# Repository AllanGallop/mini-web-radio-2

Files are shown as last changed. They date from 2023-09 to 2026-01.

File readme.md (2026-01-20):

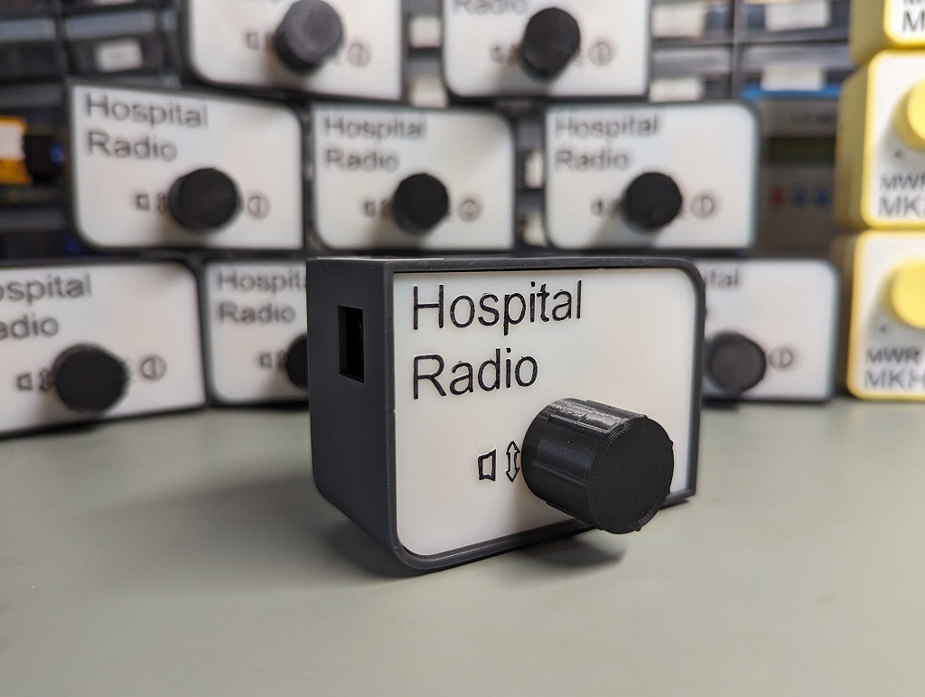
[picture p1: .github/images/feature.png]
Feature_Image


# Mini Web Radio 2

### [Version 3 now available](https://github.com/AllanGallop/mini-web-radio-3)

Originally designed as a charity project, the MWR is a simple internet radio based on the ESP32 microcontroller. Version 2 builds upon the [original project](https://github.com/AllanGallop/mini-web-radio) introducing stereo audio, supporting multiple channels and utilises a custom PCB with (mostly) surface mount components.

> Be warned, This project is still in the prototype phase

## Hardware

### Core hardware Components

* Expressif ESP32-S2 (or similar dual core variant)
* Texas Instruments PCM5102APWR audio stereo dac
* NXP TDA1308 Class AB Stereo headphone driver
* PEC12R - 12 mm Incremental Encoder
* TP4056 Lithium battery charger
* ME6211C33 500mA LDO regulator
* CH340C USB-UART

### Schematic

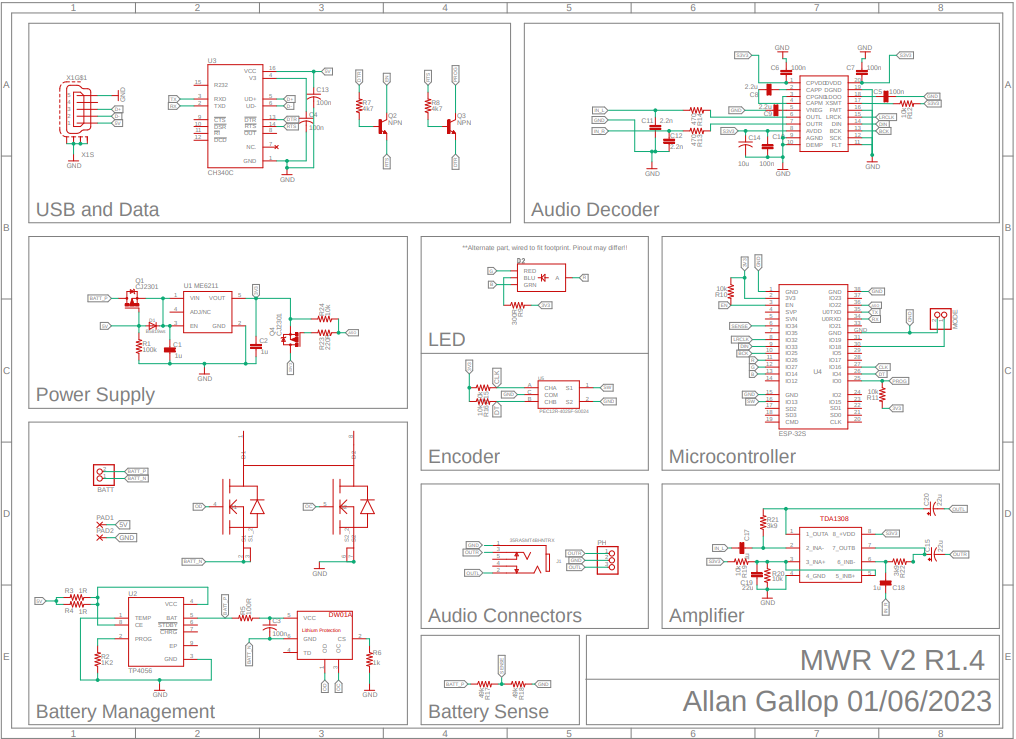
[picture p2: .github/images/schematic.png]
Schematic


## Construction

### PCB

The PCB can be produced and assembled by a fabrication service such as JLCpcb, who are also able to source a marjority of the parts. Alternatively you can fabricate the PCB and acquire / assemble it yourself. Regardless of which method chosen you will need to solder on the through-hole components yourself.. fortuently this is just the rotatry encoder and the pin headers so only minimal soldering skills are required.

All construction files, including a BOM / CPL are provided in the [pcb](pcb/) directory. Additional parts needed to complete the build are maintained in a [seperate file](pcb/additional_parts.txt).

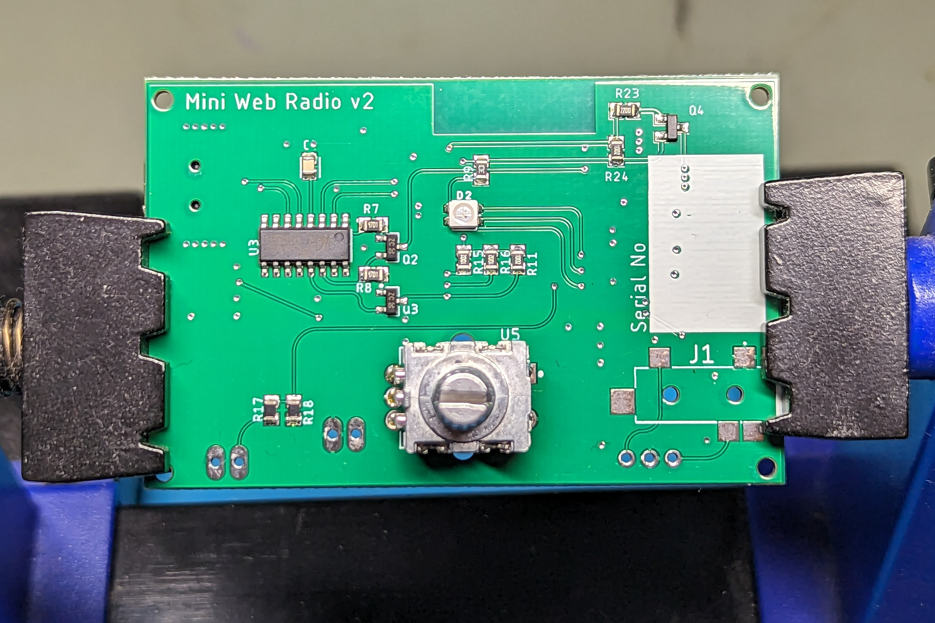
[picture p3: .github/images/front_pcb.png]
[](.github/images/front_pcb.png)
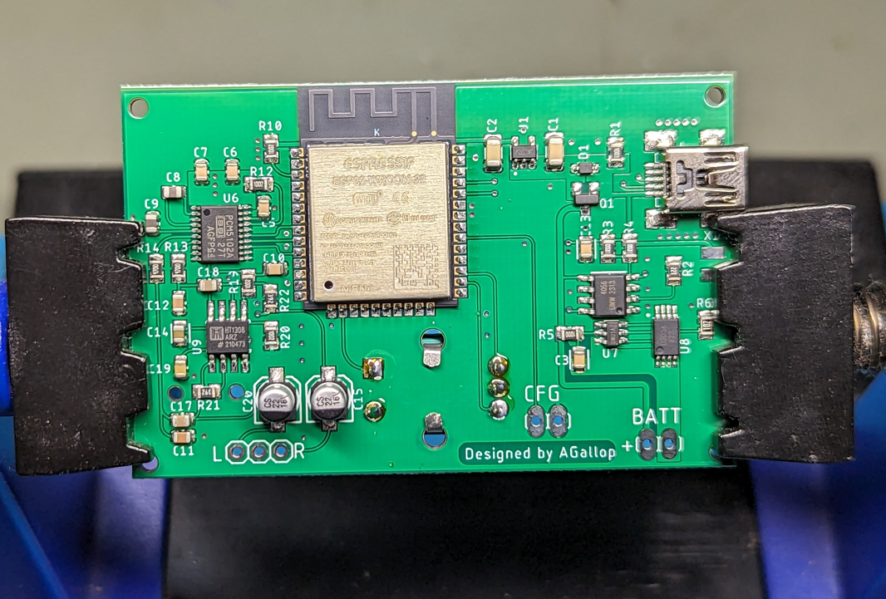
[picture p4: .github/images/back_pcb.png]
[](.github/images/back_pcb.png)

__Component Placement__

The JLCpcb assembly tool sometimes misaligns components (especially if a part is substituted). Use these images to confirm placements align with fiducial markers of the pcb. 

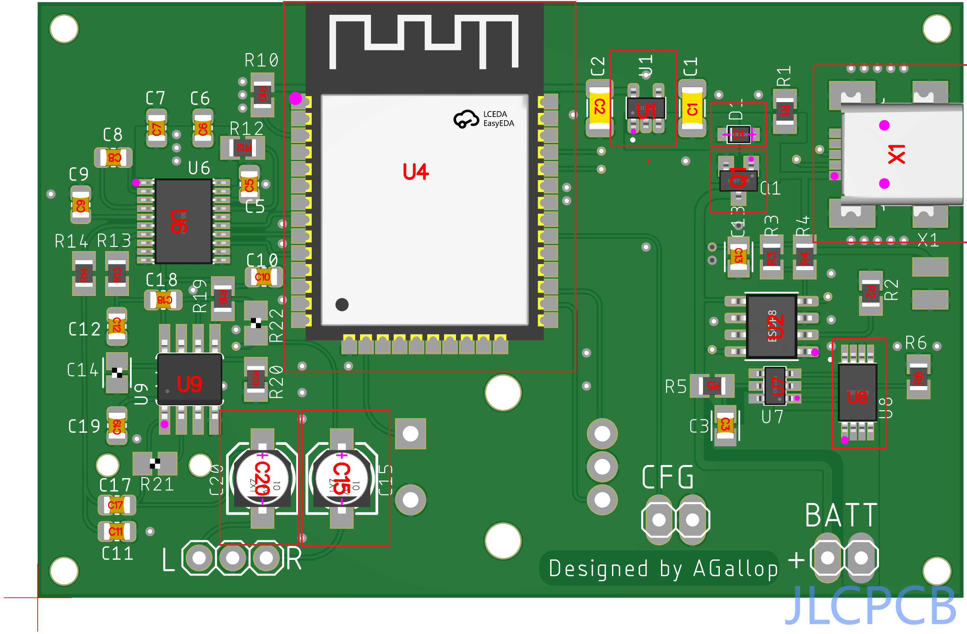
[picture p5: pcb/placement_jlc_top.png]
[](pcb/placement_jlc_top.png)
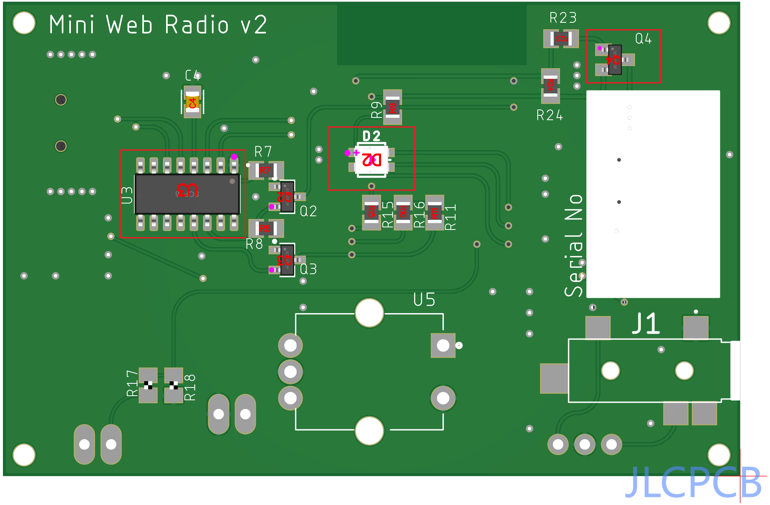
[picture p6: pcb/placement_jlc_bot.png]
[](pcb/placement_jlc_bot.png)

_Commonly misaligned are U1, D1, D2, Q1, X1, U2, U4, Q4, U8, C15 and C20_

### Case

The case is 3D printed, as above this can be done by a fabrication service if you do not own a printer. 

> Consider asking your local makerspace about 3D printing!

### Firmware

The firmware is provided in the [firmware](firmware/) directory. You will need [PlatformIO](https://platformio.org/) to build and upload it.

> Raise an issue if you would prefer an Arduino IDE version... or PR one yourself

## Operation

### Controls

The radio is designed to be easy to use, there is only one control!

* Push dial to switch it on
* Hold dial to switch it off
* Push dial while running to change channel
* Twist dial to change volume

### Status Light

| Colour | Description |
|:---|---:|
| Blue | Waiting for network |
| Green | Running - Battery Good |
| Amber | Running - Battery Reasonable |
| Red | Running - Battery Low |
| Off | Radio Off / Standby |

## Configuration

The MWR has built-in browser based configuration which allows you to define the Hostname, Wireless network credentials and the playback URL.

> Enable Configuration mode

1. Switch Off MWR
2. Open Faceplate 
3. Install jumper (2.54mm) or short config pins
4. Turn On MWR
5. Connect to `MWR-WIFI-SETUP` wireless network
6. Remove Jumper
6. Navigate browser to `192.168.1.1`
7. Enter configuration Details and select `Save`
8. The MWR will automatically restart into radio mode and begin playback

> **Use SPIFF Files** </br> Alternatively you can enter configuration details directly into the configuration files (host, ssid, pass, url) located in the _data_ directory, this is preferred when mulitiple units require setup. 

### Multiple URL's
Multiple station URL's can be entered, there should be **one** url per line. The following streams are supported:

* MP3 / M3U
* M3U8
* AAC
* FLAC
* OPUS
* OGG

### Finding URL's
There are lists available online, such as this one, however if you are unable to locate the stream URL of a preferred station I suggest locating the website in which the stream can be listened from, opening your browsers dev tools (usually F12), selecting the _Network_ and finally filter the list be 'Media' types. You may need to reload the page and start/stop playback for it to show up.

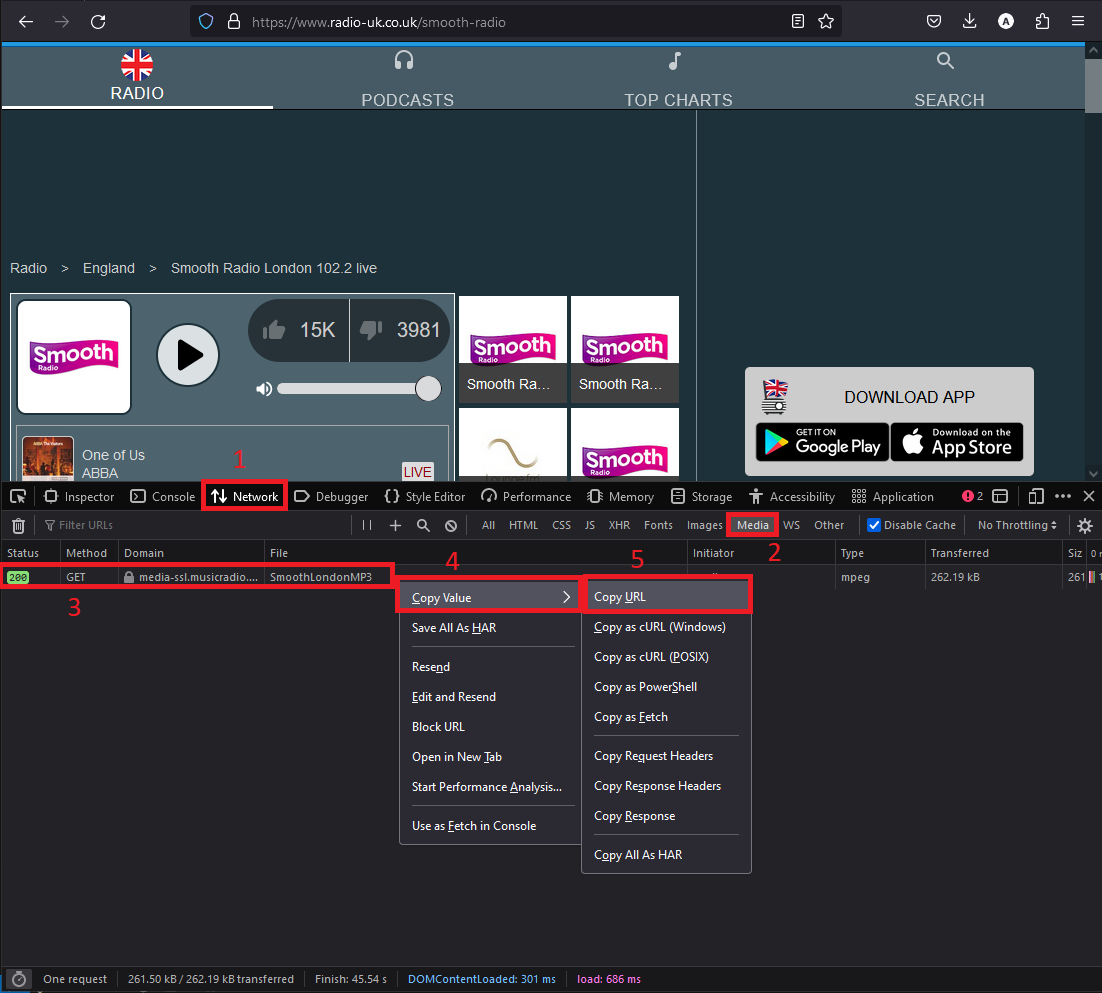
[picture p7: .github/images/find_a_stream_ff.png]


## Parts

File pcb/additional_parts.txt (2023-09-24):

Additional Parts 
====================
Quantities per radio:

4x M2x4mm Screw eg (https://www.aliexpress.com/item/32698968734.html)
1x 18650 Battery Holder eg (https://www.amazon.co.uk/WMYCONGCONG-Battery-Holder-Plastic-Storage/dp/B07QVPD9RB)
1x 18659 Battery eg (https://www.fogstar-wholesale.co.uk/product/bak-n18650cnp/)
1x 7mm Rotary Encoder (15 or 20mm) eg (https://www.aliexpress.com/item/10000056483250.html)
1x 3.5mm Stereo [TRS] 3-Pole Socket eg (https://www.aliexpress.com/item/1005005360132700.html)

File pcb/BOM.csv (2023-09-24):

Comment | Designator | Footprint | LCSC Part #
LED | D2 | LED-TRICOLOR-SMD | C601699
4k7 | R7 R8 | M0805 | C17673
10k | R11 R15 R16 R24 | M0805 | C17414
49k | R17 R18 | M0805 | C865522
220R | R23 | M0805 | C17557
300R | R9 | M0805 | C25304
CH340C | U3 | SOIC127P600X180-16N | C84681
CJ2301 | Q4 | SOT23 | C2910170
NPN | Q2 Q3 | SOT95P237X112-3N | C18536
1K2 | R2 | M0805 | C2988908
1R | R3 R4 | M0805 | C416081
1k | R6 | M0805 | C479089
1u | C1 C2 | CAP_1206 | C1848
1u | C17 C18 | CAP_0805 | C28323
2.2n | C11 C12 | CAP_0805 | C36576
2.2u | C8 C9 | CAP_0805 | C319190
3k9 | R21 R22 | M0805 | C5140081
10k | R10 R12 R19 R20 | M0805 | C17414
10u | C14 | CAP_0805 | C2835555
22u | C15 C20 | 153CLV-0505 | C98746
22u | C19 | CAP_0805 | C77071
100R | R5 | M0805 | C17408
100k | R1 | M0805 | C149504
100n | C3 C4 C5 C6 C7 C10 C13 | CAP_0805 | C476766
470R | R13 R14 | M0805 | C17710
8205A | U8 | TSSOP8 | C5148694
B5819ws | D1 | SOD-323F | C64886
CJ2301 | Q1 | SOT23 | C2910170
DW01A | U7 | SOT23-6 | C436931
ESP-32S | U4 | ESP-32S | C82899
ME6211 | U1 | SOT-23-5 | C94042
MINI-USB-SCHIELD-32005-201 | X1 | 32005-201 | C2688795
PCM5102 | U6 | TSSOP20 | C107671
TDA1308SO8 | U9 | SO8 | C2895052
TP4056 | U2 | SOP127P600X175-9N | C725790

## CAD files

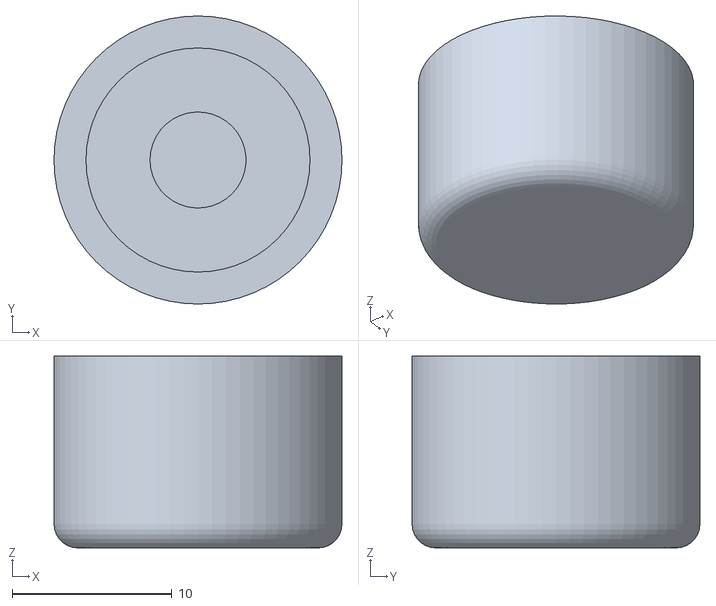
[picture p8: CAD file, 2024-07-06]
case/others/Knob_small.stl
18.0 x 18.0 x 12.0

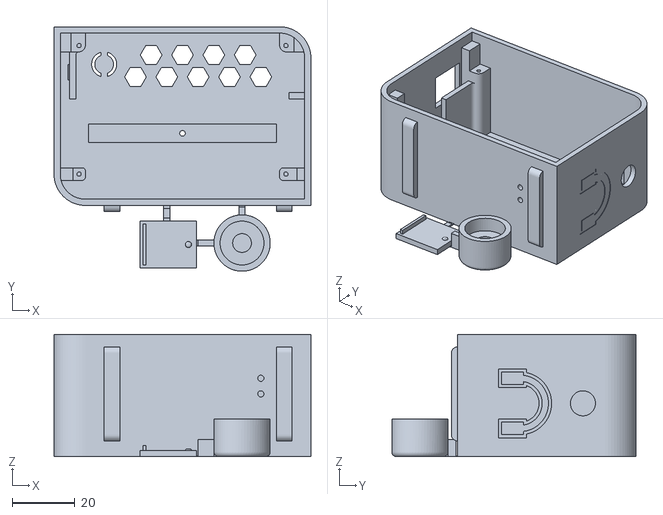
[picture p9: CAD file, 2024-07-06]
case/Shell_Combined.stl
82.0 x 78.0 x 39.0

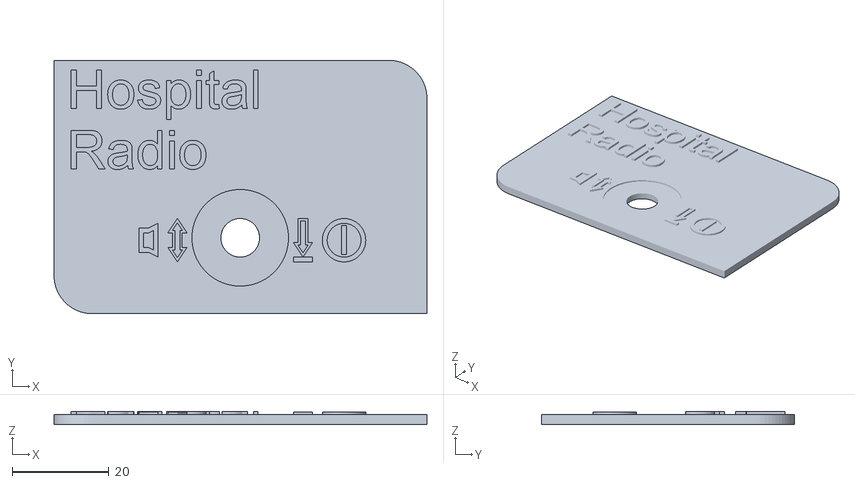
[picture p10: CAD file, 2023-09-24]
case/Face.stl
77.2 x 52.5 x 2.60

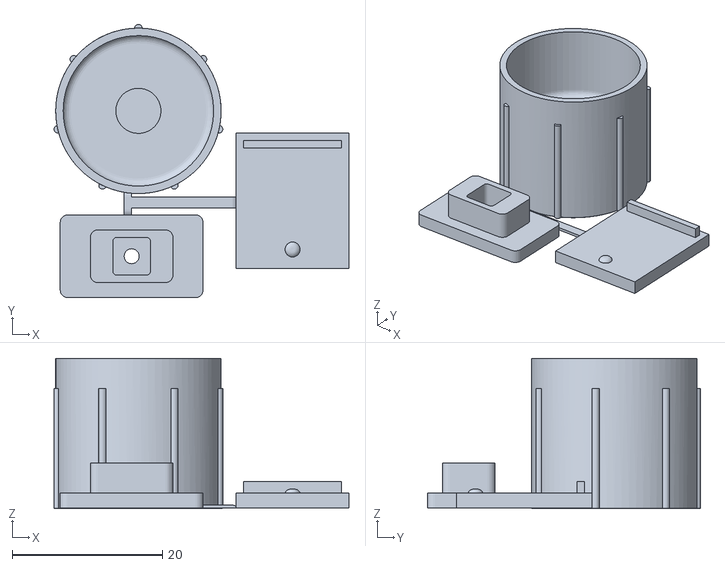
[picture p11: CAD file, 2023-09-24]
case/others/LED_Knob_Flap_Combined.stl
39.2 x 36.3 x 20.0

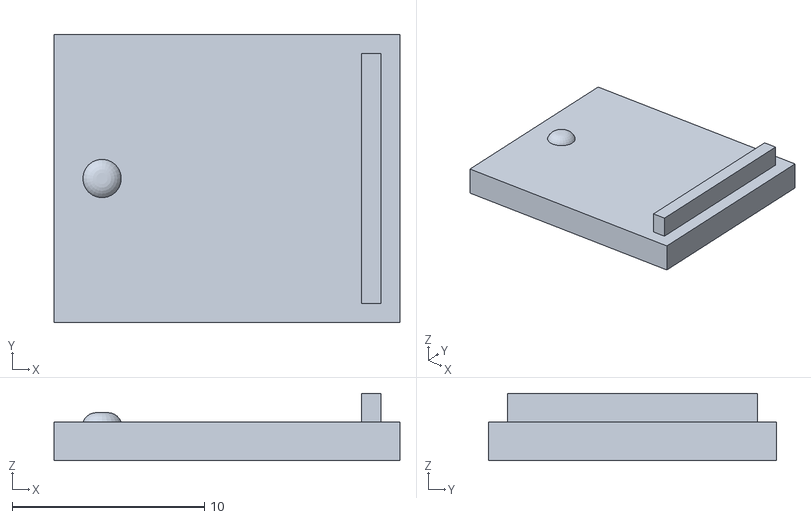
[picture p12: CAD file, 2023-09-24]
case/others/USB_Flap.stl
18.0 x 15.0 x 3.50

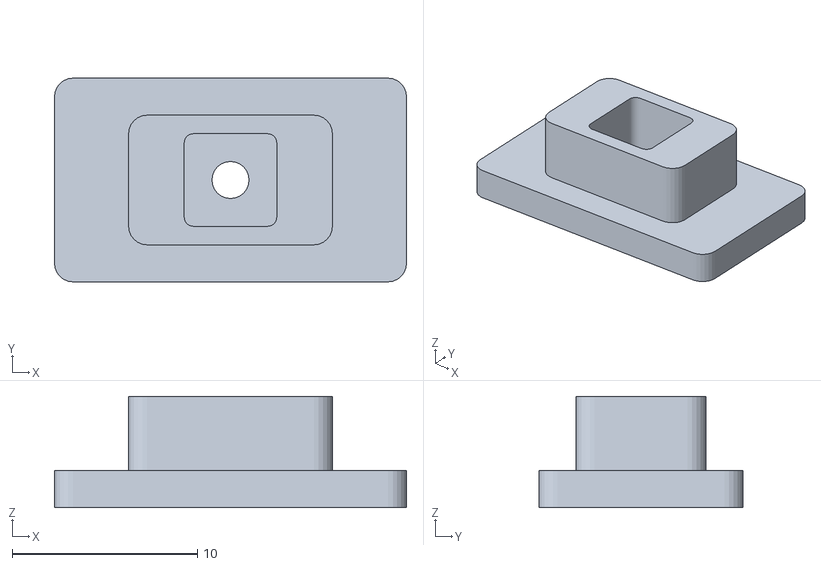
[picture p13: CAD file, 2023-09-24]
case/others/LED_Diffuser.stl
19.0 x 11.0 x 6.00

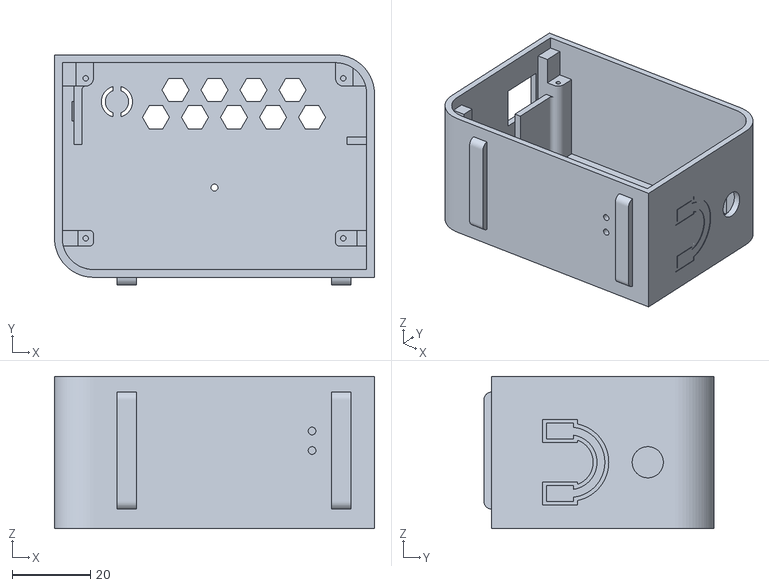
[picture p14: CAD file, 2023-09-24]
case/others/Shell.stl
82.0 x 59.0 x 39.0

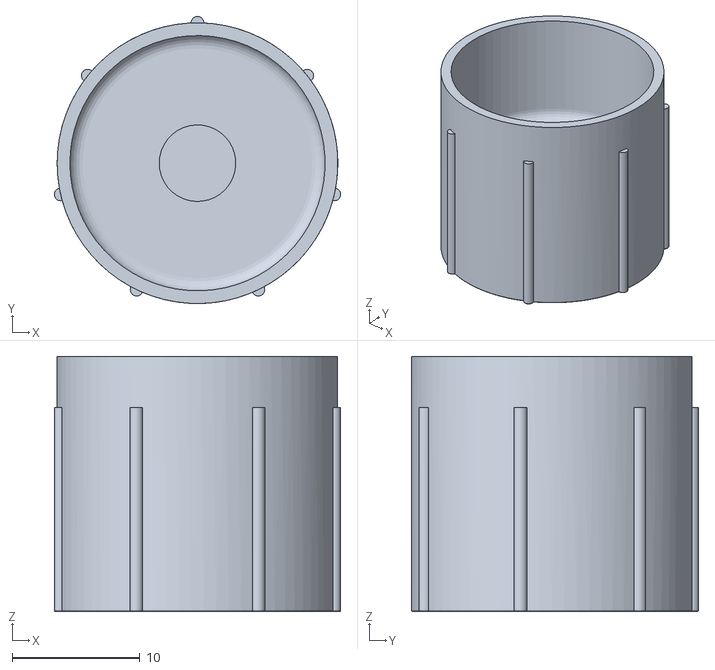
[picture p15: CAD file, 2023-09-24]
case/others/Knob_large.stl
22.4 x 22.5 x 20.0

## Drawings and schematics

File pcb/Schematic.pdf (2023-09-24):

A

A

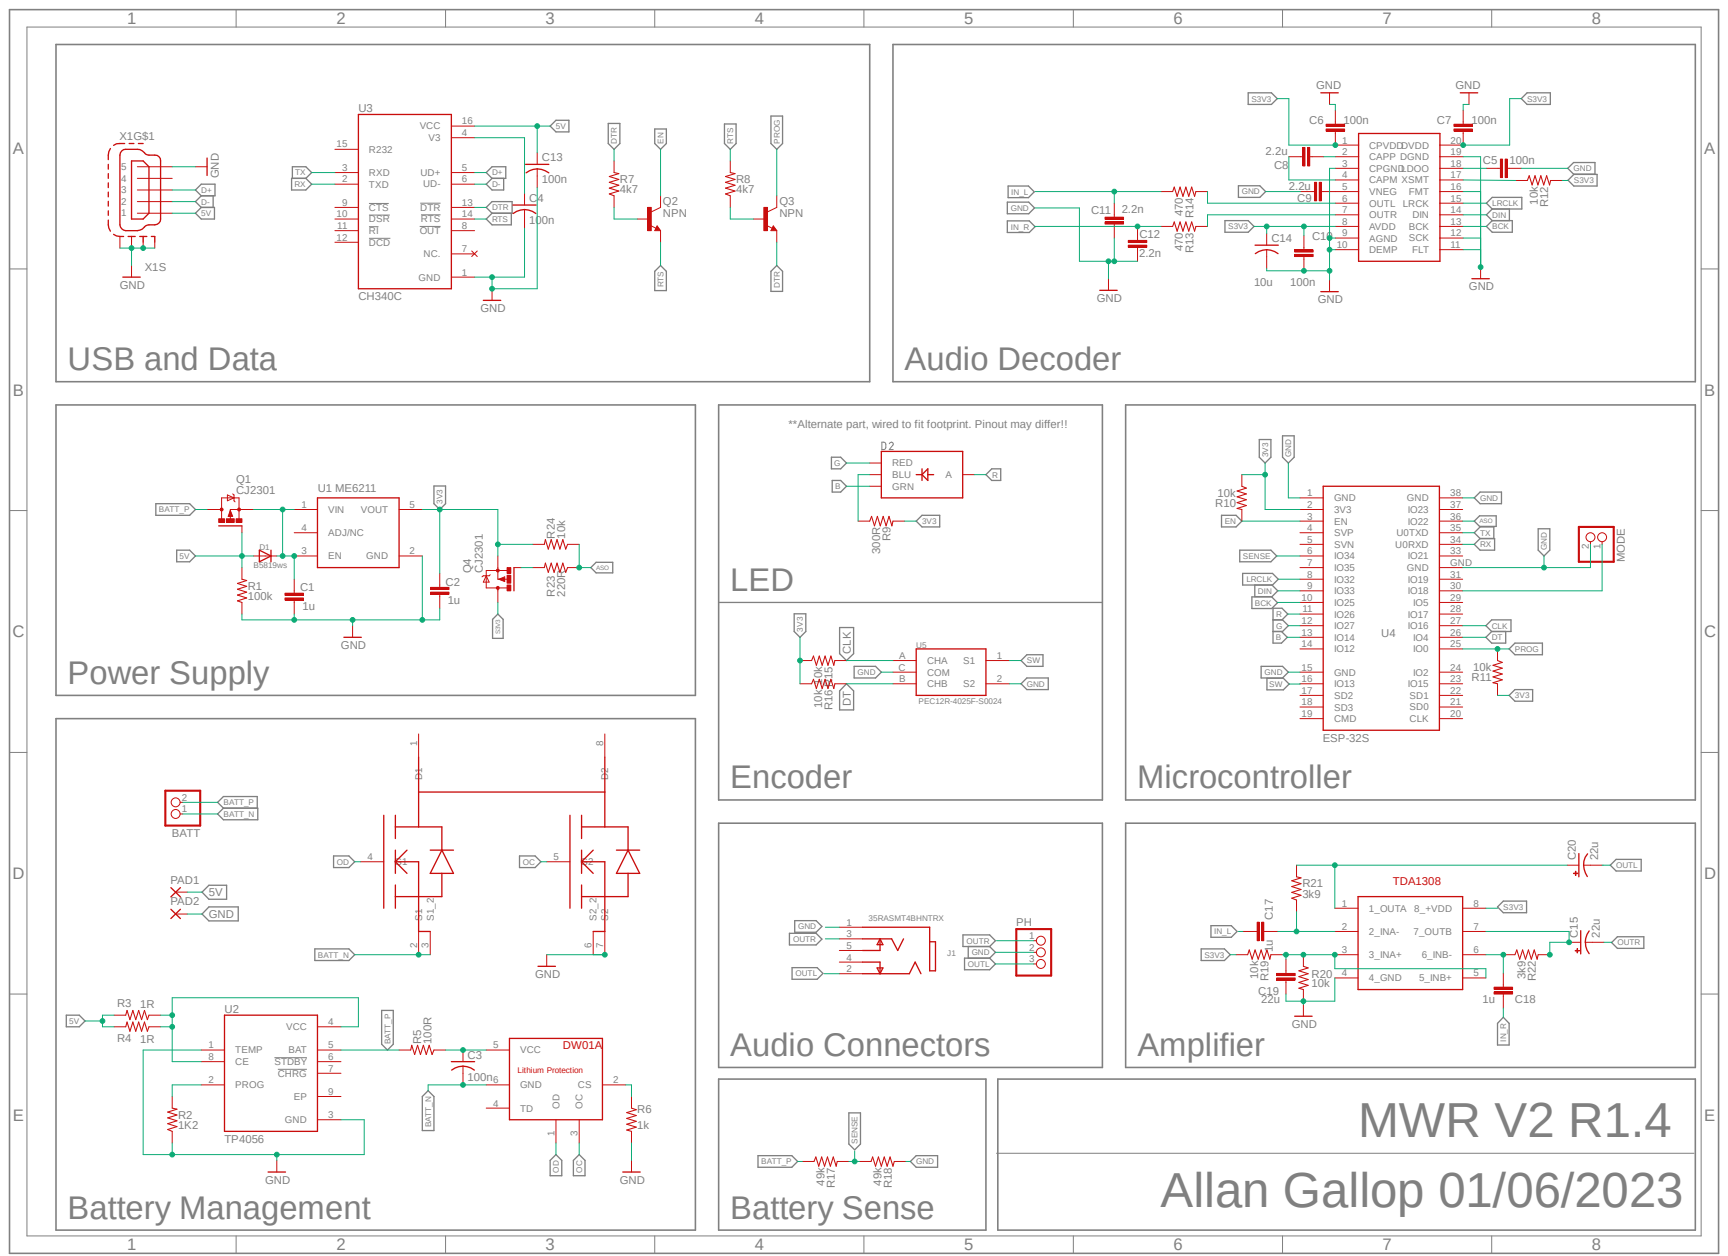
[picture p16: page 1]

**Alternate part, wired to fit footprint. Pinout may differ!!

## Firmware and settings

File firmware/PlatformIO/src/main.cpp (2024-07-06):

/**
 * @file main.cpp
 * @brief ESP32 Radio Control with Rotary Encoder and Button
 * @version 2.4
 * @date 2024-07-06
 * 
 * Mini Web Radio (v2) for MK Hospital Radio
 * 
 * For more information, visit the GitHub repository:
 * https://github.com/yourusername/your-repository
 * 
 */

// Includes
#include <Arduino.h>
#include <SPIFFS.h>
#include <WiFi.h>
#include "driver/rtc_io.h"
#include "mwr_radio.h"
#include "mwr_config.h"
#include "mwr_led.h"

// I2S
#define I2S_DOUT 33
#define I2S_BCLK 25
#define I2S_LRC 32
// LED
#define LED_G 26
#define LED_R 27
#define LED_B 14
// Encoder
#define ENC_A 4
#define ENC_B 16
#define BTN 13
// Audio Power
#define ASO 22
// Battery Sense
#define VBAT 34;
// Mode Sense
#define SMOD 18

// Globals
int longPress = 2000;
int menuState;
int mode = 0;
int volume = 8;
volatile int16_t rotationCount = 0;
unsigned long btnPressed = 0;
unsigned long btnReleased = 0;
int timer = 0;
float voltage = 0.0;

// Init MWR Libs
Config config;
Radio radio;
Led led(LED_R, LED_G, LED_B);

/**
 * @brief Set the volume of the radio.
 * 
 * @param level Volume level to set (1-64).
 */
void setVolume(int level){
    Serial.print("Volume:");
    Serial.println(level);
    radio.setVolume(level);
}

/**
 * @brief Interrupt Service Routine for the rotary encoder.
 */
void IRAM_ATTR isr_encoder() {
    static uint32_t old_state = 0x0001;
    uint8_t act_state = 0;
    uint8_t inx;
    static const int8_t enc_states[] = {
        0, -1, 1, 0,
        1, 0, 0, -1,
        -1, 0, 0, 1,
        0, 1, -1, 0
    };

    act_state = (digitalRead(ENC_A) << 1) + digitalRead(ENC_B);
    inx = (old_state << 2) + act_state;
    rotationCount += enc_states[inx];
    old_state = act_state;
}

/**
 * @brief Read the state of the button and handle press events.
 */
void read_button(){
  menuState = digitalRead(BTN);

  // Long press - shutdown radio
  if(menuState == LOW && btnPressed == 0) {
      btnPressed = millis(); 
  } else if(menuState == LOW && btnPressed > 0) {
      if((millis() - btnPressed) > longPress) { 
          btnPressed = 0; 
          led.setState("FF0000", 500, 5);
          delay(1000);
          esp_deep_sleep_start(); 
      }
  }
  
  // Short press - change station
  if(menuState == HIGH && btnPressed > 0) { 
      if((millis() - btnPressed) > 250) {
          btnPressed = 0;
          radio.next();
      }
  }

  // Check battery state
  if(timer >= 20000) {
      timer = 0;
      voltage = ((float)analogRead(34) / 4095) * 3.3 * 2 * 1.035;
      char color[6];
      sprintf(color, "33%02u00", map((voltage * 100), 310, 400, 0, 99));
      led.setColour(color);
      // Shutdown to preserve battery lifespan
      if(voltage <= 3.0) {
          led.setState("FF0000", 250, 5);
          Serial.println("Battery low, going to sleep");
          delay(1000);
          Serial.flush();
          esp_deep_sleep_start();
      }
  }
  timer++;
}

/**
 * @brief Handle WiFi disconnect events and attempt reconnection.
 * 
 * @param event WiFi event type.
 * @param info WiFi event information.
 */
void WiFiStationDisconnected(WiFiEvent_t event, WiFiEventInfo_t info) {
  led.setColour("000055");
  Serial.println("Disconnected from WiFi access point");
  Serial.println("Trying to Reconnect...");
  WiFi.reconnect();
}

void setup() {
  Serial.begin(115200);
  Serial.println("--------------------------------------");
  Serial.println("MWR Version 2");
  Serial.print("MAC Address:");
  Serial.println(WiFi.macAddress());
  Serial.println("--------------------------------------");


  // Setup RTC Wake
  rtc_gpio_pullup_en(GPIO_NUM_13);
  rtc_gpio_pulldown_dis(GPIO_NUM_13);
  esp_sleep_enable_ext0_wakeup(GPIO_NUM_13, 0);

  // Setup GPIO
  pinMode(ASO, OUTPUT); 
  pinMode(SMOD, INPUT_PULLUP);
  pinMode(BTN, INPUT_PULLUP);
  pinMode(ENC_A, INPUT_PULLUP);
  pinMode(ENC_B, INPUT_PULLUP);

  // Attach Interrupts
  attachInterrupt(ENC_A, isr_encoder, CHANGE);
  attachInterrupt(ENC_B, isr_encoder, CHANGE);

  // Initialise audio
  radio.init(I2S_DOUT, I2S_BCLK, I2S_LRC, ASO);

  // Handle wifi disconnect
  WiFi.onEvent(WiFiStationDisconnected, WiFiEvent_t::ARDUINO_EVENT_WIFI_STA_DISCONNECTED);

  // Check and set boot state
  if(digitalRead(SMOD)) {
      config.stMode();
      String url = radio.readLine(0);
      radio.setVolume(volume);
      radio.setStation(url);
      int treble = config.getTreble();
      int mid = config.getMid();
      int bass = config.getBass();
      radio.setTone(bass, mid, treble);
      radio.next();
  } else {
      config.apMode();
  }

  delay(1000);
}

void loop() {

    read_button();

    if (WiFi.status() == WL_CONNECTED) {
      radio.play();
    }else{
      Serial.println("Offline");
      delay(500);
    }
    
    static int16_t lastRotationCount = 0;
    if (rotationCount != lastRotationCount) {
        noInterrupts();
        int16_t rotation = rotationCount;
        rotationCount = 0;
        interrupts();

        if (rotation >= 1) {
            if (volume < 64) { volume++; }
            setVolume(volume);
        } else if (rotation <= -1) {
            if (volume > 1) { volume--; }
            setVolume(volume);
        }
        lastRotationCount = rotation;
    }
}

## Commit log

2023-09-24 First Commit
    added component placement images
    updated read me with component placement
    fixed incorrect L channel path
    Updated schematic to reflect L channel patch changes
    [BOM.csv, Face.stl, Knob.stl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]
2024-07-06 Fixes encoder, adds tone, updates config menu
    [main.cpp]
2024-07-06 Adds combined case model
    [Knob_large.stl, Knob_small.stl, LED_Diffuser.stl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]
